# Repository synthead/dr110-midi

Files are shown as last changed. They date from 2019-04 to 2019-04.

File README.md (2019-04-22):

# Synthead BOSS DR-110 MIDI Retrofit

This is an open, Arduino-based project that adds MIDI to your BOSS DR-110!



## Features

This retrofit supports:

- **MIDI sync** via MIDI start, stop, continue, and beat clock messages to play patterns programmed on the DR-110's internal sequencer in time.
- **MIDI note on** messages to play individual drum sounds in an external sequencer.  The General MIDI note mapping is followed.

## How it works

### MIDI sync

The START and STOP buttons on the front panel are "pressed" to MIDI start and stop messages, and a clock is generated to keep the internal sequencer in time with MIDI beat clock messages.  There is also a transistor on the retrofit that restores the internal clock when MIDI sync is not being used.

### MIDI notes

The key matrix for the front panel was reverse-engineered, and this retrofit "presses" the buttons on incoming MIDI note on messages.  This means that it's also possible to program the DR-110's internal sequencer in tap write mode over MIDI using either the internal clock or while the sequencer is synchronized to MIDI sync messages.

## Building a board

The retrofit is built on a small, single-sided PCB using only generic, through-hole components.  This makes it more accessible for it to be built at home.  The copper and silkscreen renders can be found in the [`KiCad/rendered/`](https://github.com/synthead/dr110-midi/tree/master/KiCad/rendered/) directory.

The board needs to be built as low-profile as possible.  The transistors should have their legs bent at right angles, and the Arduino Pro Micro board should lay directly on the surface of the PCB, preferably with small pieces of solid wire connecting the PCBs together.

### Parts list

| Reference | Part number |
|---|---|
| Q1-7 | BC547 |
| R1-7 | 1-10K |
| R8, 10 | 220 |
| R9 | 4.7K |
| D1 | 1N4148 |
| U1 | 6N138 |
| U2 | Arduino Pro Micro |

When built, it'll produce a board like this:




## Installation

Solder stranded wire to the connections of J1 and solder them onto the solder joints as pictured below.  While doing so, separate the fourth wire off of the ribbon cable between the CPU and voice board with a razor blade, remove it, and solder CI and CO to the through holes.



Then, solder stranded wire to J2 and connect them to pins 4 and 5 of a female chassis mount DIN-5 connector for MIDI input.  It is also possible to mount a USB connection to the exterior of the DR-110 to provide updates to the retrofit without opening the unit (see the [Amphoenol MUSBB55104](https://www.arrow.com/en/products/musbb55104/amphenol) connector).

The DIN-5 and USB connectors fit neatly in the bottom-left corner of the DR-110 by the battery compartment.  The retrofit should be insulated, preferably with heatshrink.  It's a tight fit when installed and fits best with the position in the picture below.  Move it around slightly until it fits snug with the DR-110 components, then carefully close the machine.



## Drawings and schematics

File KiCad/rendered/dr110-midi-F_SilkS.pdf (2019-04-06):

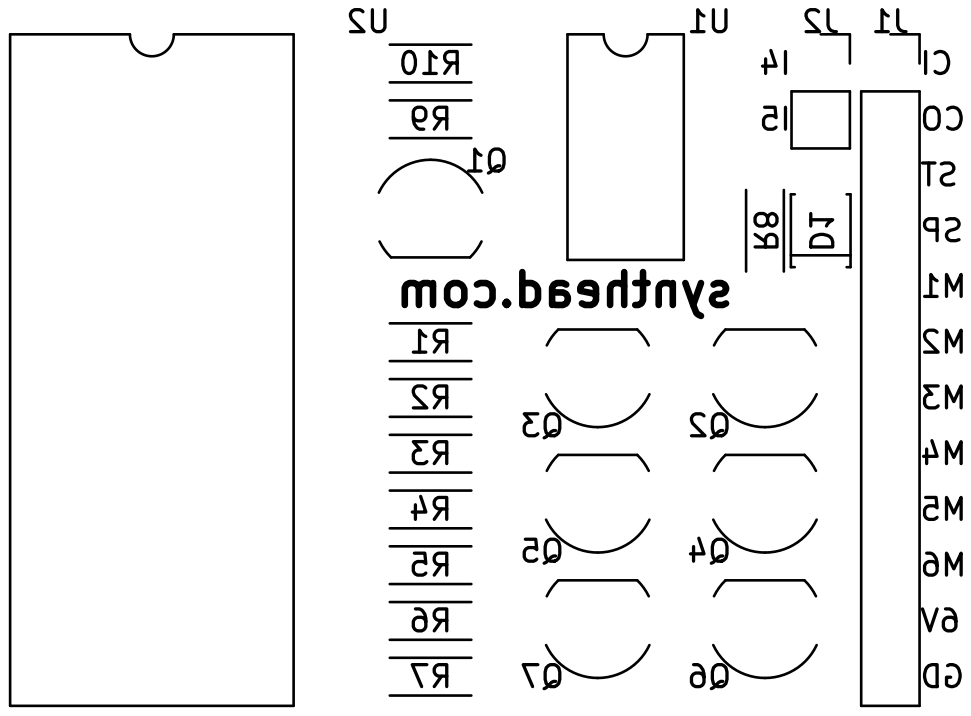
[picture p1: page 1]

CI 6V GD synthead.com

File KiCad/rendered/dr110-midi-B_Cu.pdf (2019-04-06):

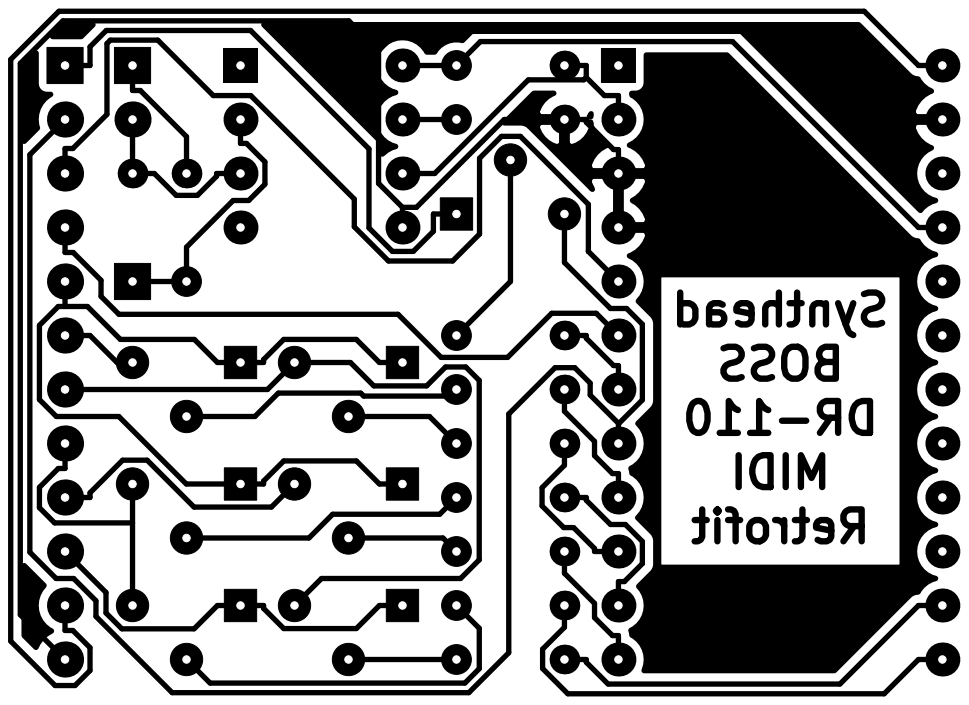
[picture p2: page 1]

Synthead BOSS DR-110 MIDI Retrofit

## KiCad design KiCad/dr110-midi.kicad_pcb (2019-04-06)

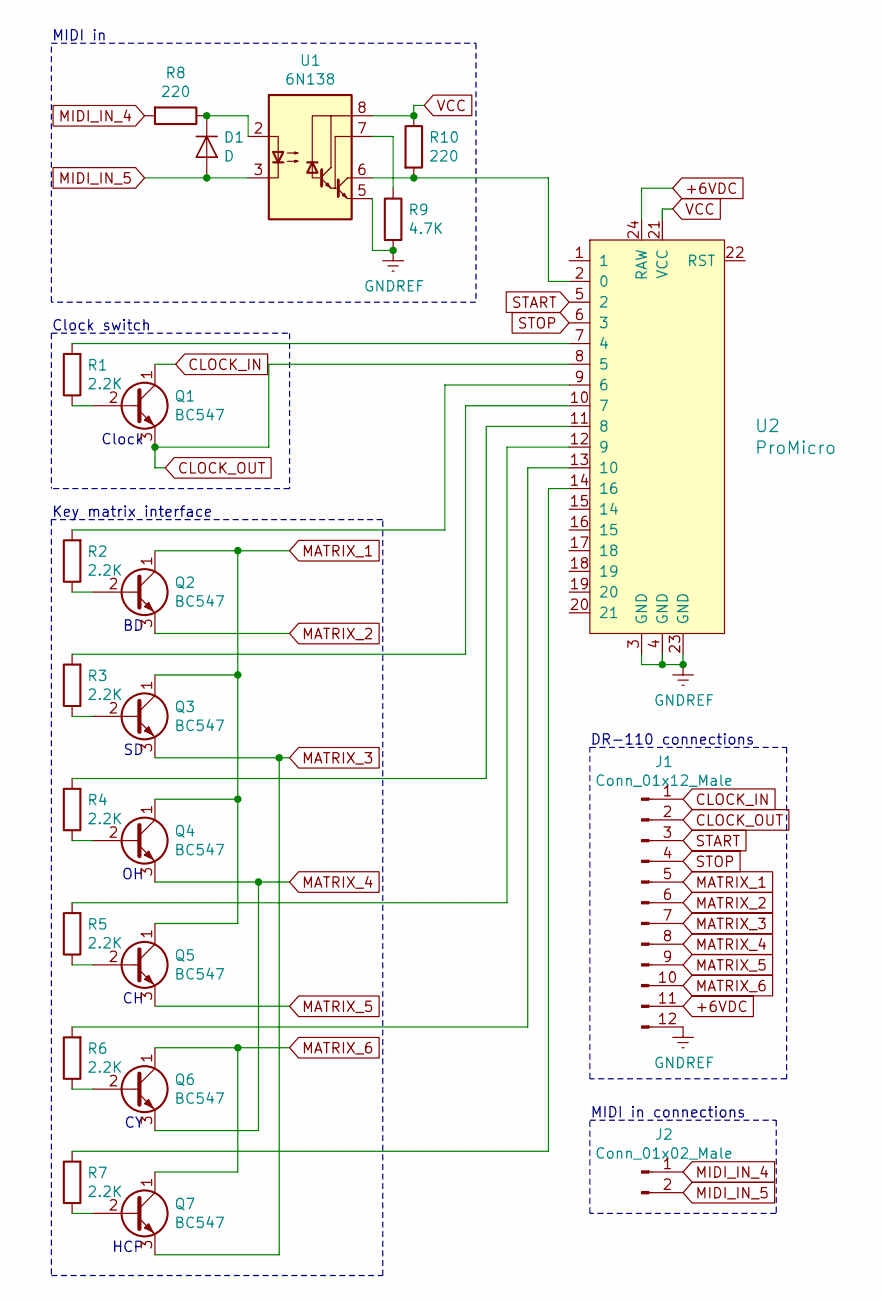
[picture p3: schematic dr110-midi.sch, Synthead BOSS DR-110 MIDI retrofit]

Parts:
D1: D; D_DO-35_SOD27_P5.08mm_Vertical_KathodeUp
J1: Conn_01x12_Male; Socket_Strip_Straight_1x12_Pitch2.54mm
J2: Conn_01x02_Male; Socket_Strip_Straight_1x02_Pitch2.54mm
Q1, Q2, Q3, Q4, Q5, Q6, Q7: BC547; TO-92_Molded_Wide
R1, R2, R3, R4, R5, R6, R7: 2.2K; R_Axial_DIN0204_L3.6mm_D1.6mm_P5.08mm_Horizontal
R8, R10: 220; R_Axial_DIN0204_L3.6mm_D1.6mm_P5.08mm_Horizontal
R9: 4.7K; R_Axial_DIN0204_L3.6mm_D1.6mm_P5.08mm_Horizontal
U1: 6N138; DIP-8_W7.62mm
U2: ProMicro

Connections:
+6VDC: J1.11, U2.24 (RAW)
CLOCK_IN: J1.1, Q1.1 (C)
CLOCK_OUT: J1.2, Q1.3 (E), U2.8 (5)
GNDREF: J1.12, R9.2, U1.5 (GND), U2.3 (GND), U2.4 (GND), U2.23 (GND)
MATRIX_1: J1.5, Q2.1 (C), Q3.1 (C), Q4.1 (C), Q5.1 (C)
MATRIX_2: J1.6, Q2.3 (E)
MATRIX_3: J1.7, Q3.3 (E), Q7.3 (E)
MATRIX_4: J1.8, Q4.3 (E), Q6.3 (E)
MATRIX_5: J1.9, Q5.3 (E)
MATRIX_6: J1.10, Q6.1 (C), Q7.1 (C)
MIDI_IN_4: J2.1, R8.2
MIDI_IN_5: D1.2 (A), J2.2, U1.3 (C2)
unnamed: D1.1 (K), R8.1, U1.2 (C1)
unnamed: Q1.2 (B), R1.1
unnamed: Q2.2 (B), R2.1
unnamed: Q3.2 (B), R3.1
unnamed: Q4.2 (B), R4.1
unnamed: Q5.2 (B), R5.1
unnamed: Q6.2 (B), R6.1
unnamed: Q7.2 (B), R7.1
unnamed: R1.2, U2.7 (4)
unnamed: R2.2, U2.9 (6)
unnamed: R3.2, U2.10 (7)
unnamed: R4.2, U2.11 (8)
unnamed: R5.2, U2.12 (9)
unnamed: R6.2, U2.13 (10)
unnamed: R7.2, U2.14 (16)
unnamed: R9.1, U1.7 (VO1)
unnamed: R10.2, U1.6 (VO2), U2.2 (0)
START: J1.3, U2.5 (2)
STOP: J1.4, U2.6 (3)
VCC: R10.1, U1.8 (VCC), U2.21 (VCC)

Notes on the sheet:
Clock switch
Clock
DR-110 connections
MIDI in
MIDI in connections
HCP
Key matrix interface

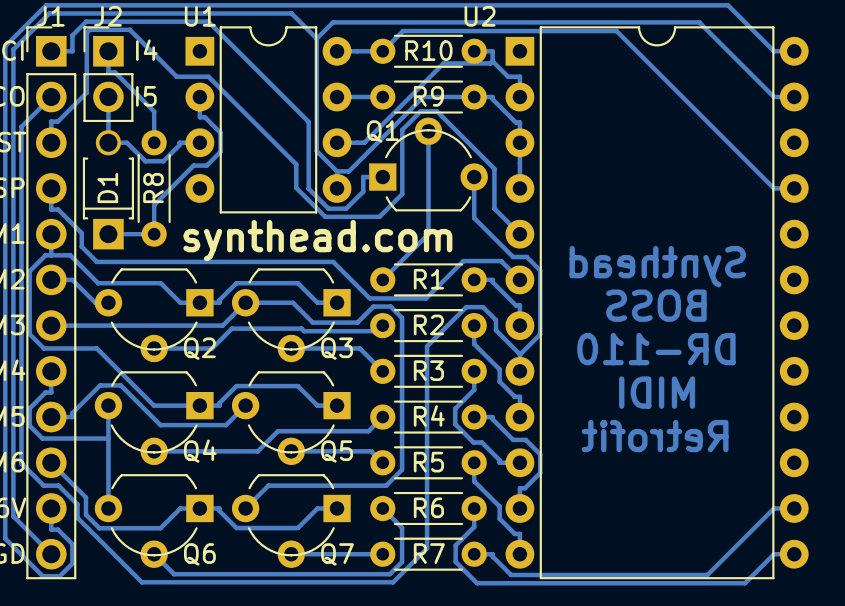
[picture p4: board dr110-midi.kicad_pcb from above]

Board: 2 copper layers, 22 parts (0 on the bottom side), 32 nets.

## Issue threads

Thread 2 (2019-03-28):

Check time with millis() instead of using delay() for button pushes

synthead, 2019-03-28:

synthead, 2019-04-22:
Fixed in https://github.com/synthead/dr110-midi/commit/d06ca1d530cb6c93f170a8d0839f97d0c9ad4f38.

Closed 2019-04-22.

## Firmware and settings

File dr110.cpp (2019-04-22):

#include "dr110.h"
#include <Arduino.h>

namespace Dr110 {
  bool clock_state;
  uint8_t triggers[] = {
    DR110_START_PIN,
    DR110_STOP_PIN,
    DR110_BD_PIN,
    DR110_SD_PIN,
    DR110_OH_PIN,
    DR110_CH_PIN,
    DR110_CY_PIN,
    DR110_HCP_PIN
  };
  bool triggered[16];
  unsigned long triggered_at[16];

  uint8_t trigger_i;
  uint8_t trigger;
  unsigned long now;
  unsigned long trigger_expires_at;
  uint8_t delay;

  void setup() {
    pinMode(DR110_START_PIN, OUTPUT);
    pinMode(DR110_STOP_PIN, OUTPUT);
    pinMode(DR110_INT_CLOCK_PIN, OUTPUT);

    pinMode(DR110_BD_PIN, OUTPUT);
    pinMode(DR110_SD_PIN, OUTPUT);
    pinMode(DR110_OH_PIN, OUTPUT);
    pinMode(DR110_CH_PIN, OUTPUT);
    pinMode(DR110_CY_PIN, OUTPUT);
    pinMode(DR110_HCP_PIN, OUTPUT);

    set_internal_clock(true);
  }

  void iterate_triggers() {
    for (trigger_i = 0; trigger_i < DR110_TRIGGERS; trigger_i++) {
      trigger = triggers[trigger_i];
      now = millis();

      if (triggered[trigger]) {
        delay = (
          trigger == DR110_START_PIN || trigger == DR110_STOP_PIN ?
          DR110_START_STOP_PULSE_DELAY :
          DR110_PULSE_DELAY
        );

        trigger_expires_at = triggered_at[trigger] + delay;

        if (now > trigger_expires_at) {
          digitalWrite(trigger, LOW);
        }
      }
    }
  }

  void start() {
    set_internal_clock(false);
    reset_clock();

    pulse(DR110_START_PIN);
  }
  
  void stop() {
    pulse(DR110_STOP_PIN);

    set_internal_clock(true);
  }
  
  void pulse(int pin) {
    triggered[pin] = true;
    triggered_at[pin] = millis();

    digitalWrite(pin, HIGH);
  }

  void set_internal_clock(bool enable) {
    clock_state = true;

    bool clock_pin_mode = enable ? INPUT : OUTPUT;
    pinMode(DR110_CLOCK_PIN, clock_pin_mode);

    digitalWrite(DR110_INT_CLOCK_PIN, enable);
  }

  void reset_clock() {
    clock_state = true;
    set_clock_state();
  }

  void iterate_clock() {
    clock_state = !clock_state;
    set_clock_state();
  }

  void set_clock_state() {
    digitalWrite(DR110_CLOCK_PIN, clock_state);
  }

  void bd() {
    pulse(DR110_BD_PIN);
  }

  void sd() {
    pulse(DR110_SD_PIN);
  }

  void oh() {
    pulse(DR110_OH_PIN);
  }

  void ch() {
    pulse(DR110_CH_PIN);
  }

  void cy() {
    pulse(DR110_CY_PIN);
  }

  void hcp() {
    pulse(DR110_HCP_PIN);
  }
}

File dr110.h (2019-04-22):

#ifndef DR110_H
#define DR110_H

#define DR110_START_PIN 2
#define DR110_STOP_PIN 3
#define DR110_INT_CLOCK_PIN 4
#define DR110_CLOCK_PIN 5

#define DR110_BD_PIN 6
#define DR110_SD_PIN 7
#define DR110_OH_PIN 8
#define DR110_CH_PIN 9
#define DR110_CY_PIN 10
#define DR110_HCP_PIN 16

#define DR110_TRIGGERS 8
#define DR110_PULSE_DELAY 15
#define DR110_START_STOP_PULSE_DELAY 50

namespace Dr110 {
  void setup();
  void iterate_triggers();
  void start();
  void stop();
  void pulse(int);
  void set_internal_clock(bool);
  void reset_clock();
  void iterate_clock();
  void set_clock_state();

  void bd();
  void sd();
  void oh();
  void ch();
  void cy();
  void hcp();
}

#endif

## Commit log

2019-04-03 Add KiCad project.
    [dr110-midi.dsn, dr110-midi.kicad_pcb, dr110-midi.sch]
2019-04-04 Fix key matrix transistor pinouts.
    [dr110-midi.dsn, dr110-midi.kicad_pcb, dr110-midi.sch]
2019-04-04 Add silkscreen text for connection pinouts.
    [dr110-midi.kicad_pcb]
2019-04-06 Add drill guides to copper side.
    [dr110-midi.kicad_pcb]
2019-04-06 Add render of silkscreen with connector labels.
2019-04-22 Don't halt code when pressing buttons.
2019-04-22 Fix START and STOP buttons not being released.
    [dr110.cpp, dr110.h]
2019-04-22 Use 50 ms button press time for START and STOP.
2019-04-22 Correct resistor references in parts list.
